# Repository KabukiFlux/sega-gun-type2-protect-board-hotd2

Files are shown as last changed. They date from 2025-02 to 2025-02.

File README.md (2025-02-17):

# SEGA Gun type II Input Protection Board for *The House of the Dead 2* 

This repository contains the **KiCAD project files** for the **Gun II Input Protection Board (GIPB)**, a component designed to help protect the gun sensors in *The House of the Dead 2* arcade machines. The design is based on SEGA's **Service Bulletin (09/10/2002)**, which introduced this board to prevent or minimize damage to the **Gun Sense Board** and **LED Boards** caused by connection issues.

## Table of contents

- [Why](#why)
- [Description](#-description)
- [Schematics](#-schematics)
- [Installation Guide](#-installation-guide)
- [Repository contents](#-repository-contents)

## Why?

This was done during some live events on Twitch.tv and tested for some time.

This is a must have for people using the arcade cabinet for guns on a hostile environment

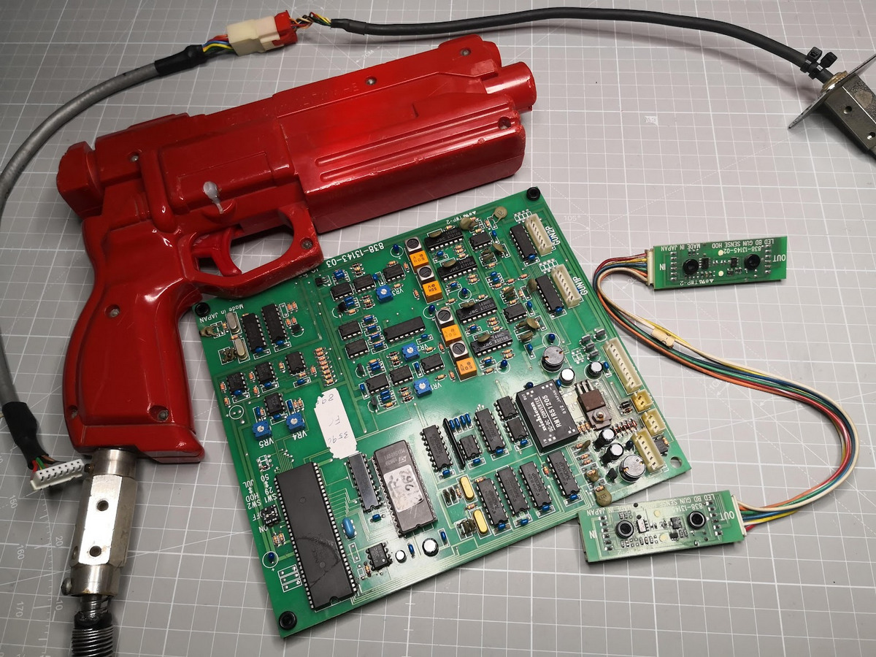
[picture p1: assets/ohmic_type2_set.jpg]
OHMIC Set


## 📜 Description

Over time, disconnections or improper handling of the gun harnesses can lead to damage in the **Gun Sense Board** or **LED Boards**, potentially rendering the guns non-functional. SEGA introduced this **Gun Input Protection Board** to mitigate this issue. While it **does not repair faulty hardware**, it acts as a safeguard against further damage, extending the lifespan of the arcade cabinet's gun system.  

- **Protects the Gun Sense Board & LED Boards** from connection-related damage  
- **Compatible with original HOTD2 and JPLW arcade hardware**  
- **Straightforward installation** – integrates between the gun harness and the Gun Sense Board  
- **Includes KiCAD project files** for custom PCB manufacturing  

## 📝 Schematics

This is the schematics:

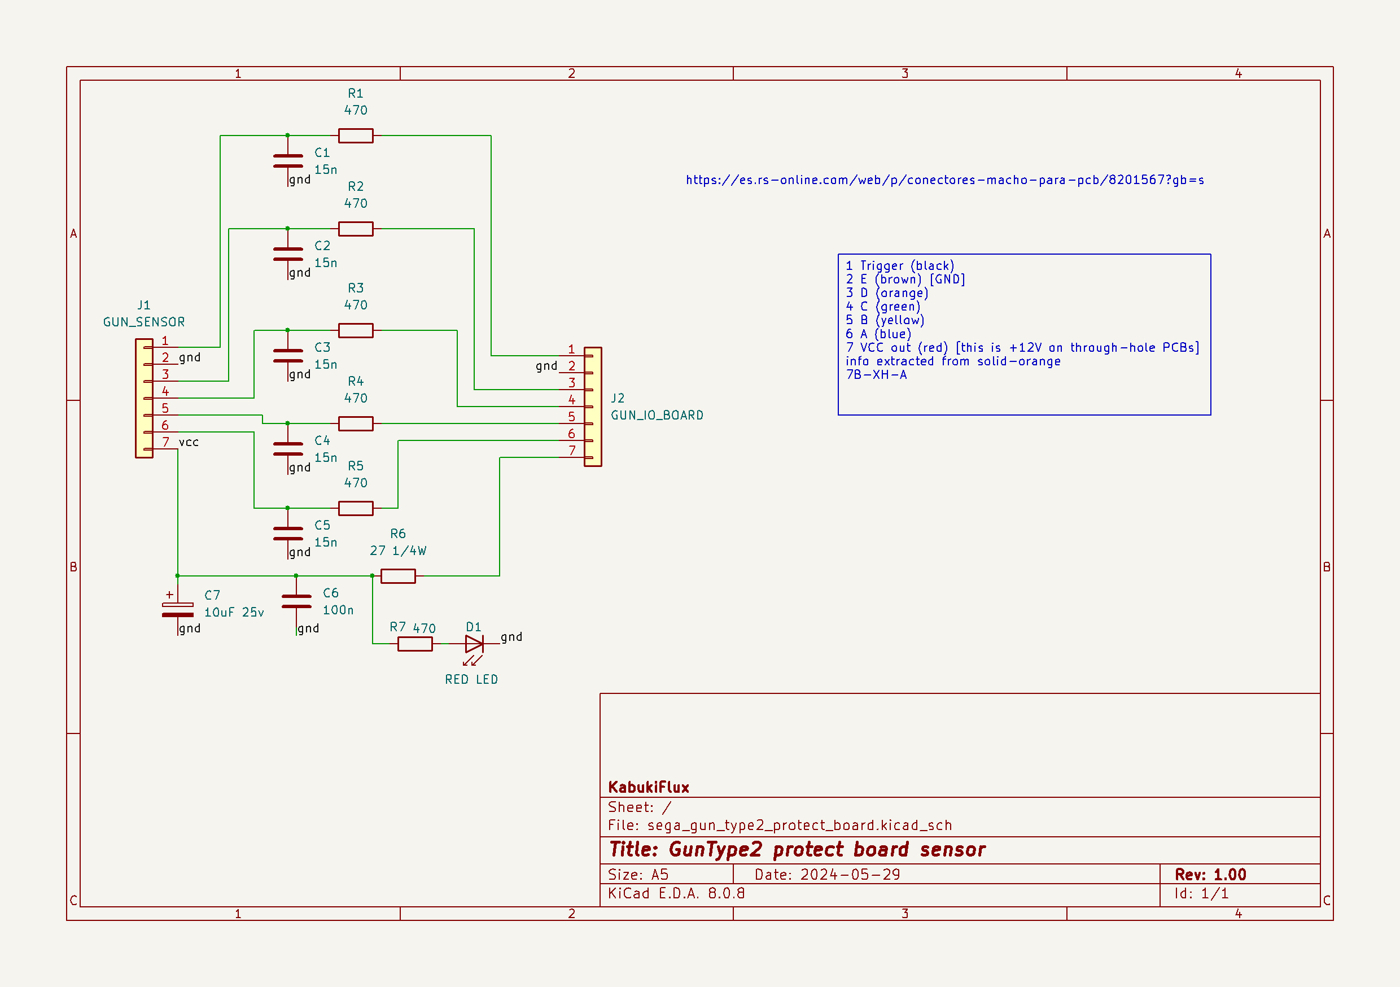
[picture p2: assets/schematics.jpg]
Schematics


## 🛠️ Installation Guide  

### 1️⃣ Preparation  

1- Send to manufacture the GERBER board to [JLCPCB](https://jlcpcb.com/) or other PCB manufacturer.

2- Get the components required, you can see here the Bill Of Materials [BOM](bom/ibom.html)

3- Solder the components.

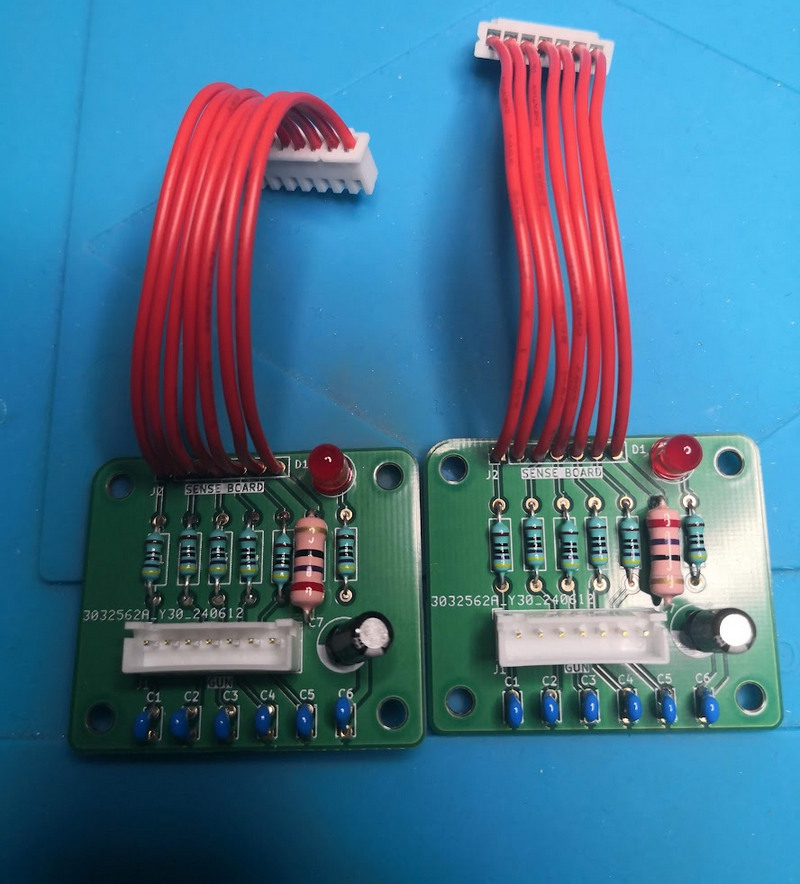
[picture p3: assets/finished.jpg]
Gun protect board


Before installing the board, ensure that:  
- The **Gun Sense Board** and **guns are fully functional**  
- The **arcade cabinet is powered off**  

### 2️⃣ Installation Steps  
1. Locate the **Gun Sense Board** inside the arcade machine.  
2. Disconnect the gun harnesses from the **GUN1P** and **GUN2P** ports.  
3. Take the **Gun Input Protection Board (GIPB)** and connect its labeled **GUN1P** and **GUN2P** connectors to the corresponding ports on the **Gun Sense Board**.  
4. Reconnect Player 1’s (Blue Gun) harness into **GUN1P** on the **Protection Board**.  
5. Reconnect Player 2’s (Red Gun) harness into **GUN2P** on the **Protection Board**.  
6. Secure the **Protection Board** using the provided spacers and screws.  
7. Power on the arcade cabinet and enter **Self-Test Mode**.  
8. Navigate to **Gun Settings** and recalibrate the guns.  

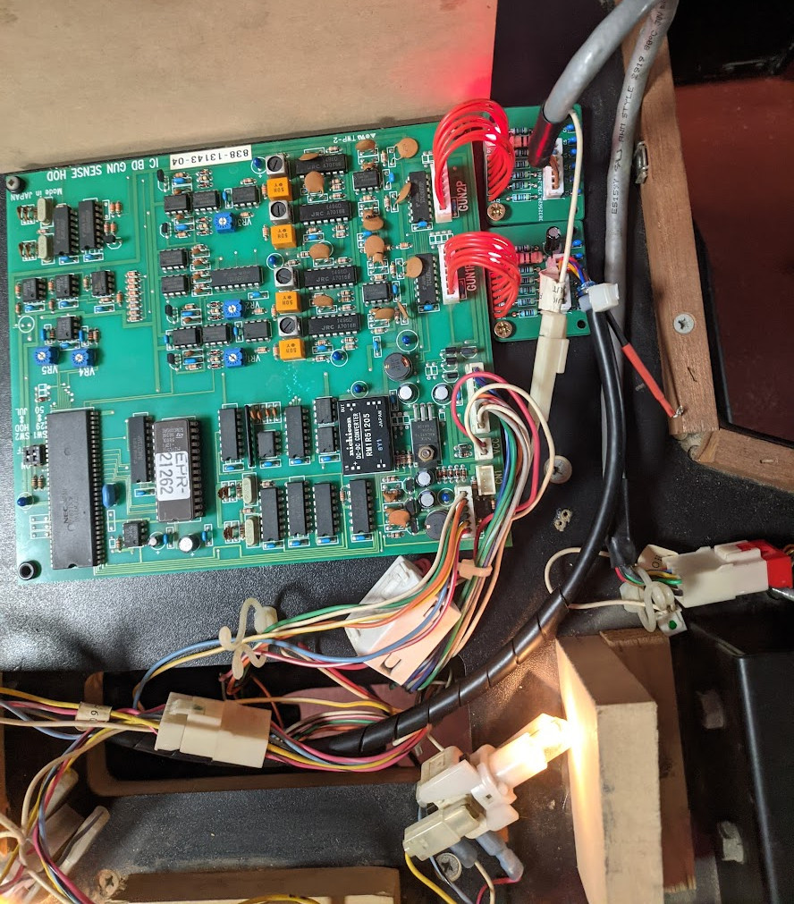
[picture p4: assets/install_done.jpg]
Finished install


## 📝 Repository Contents  

- **`/kicad/`** – KiCAD design files for the **Gun Input Protection Board**  
- **`/bom/`** – Circuit parts and assembly for reference  
- **`/gerbers/`** – Gerber files for PCB fabrication  
- **`/DOC/`** – Original bulletin

## 📢 Disclaimer  

I'm not responsible
===================
And yes, read below, no liability is assumed for misuse.

DISCLAIMER (See Licensing)
==========================
See LICENSE fo more information. 

This project is intended for preservation and repair purposes. **Use at your own risk.** The original SEGA hardware must be in **good working condition** before installation. This repository is **not affiliated with SEGA**.

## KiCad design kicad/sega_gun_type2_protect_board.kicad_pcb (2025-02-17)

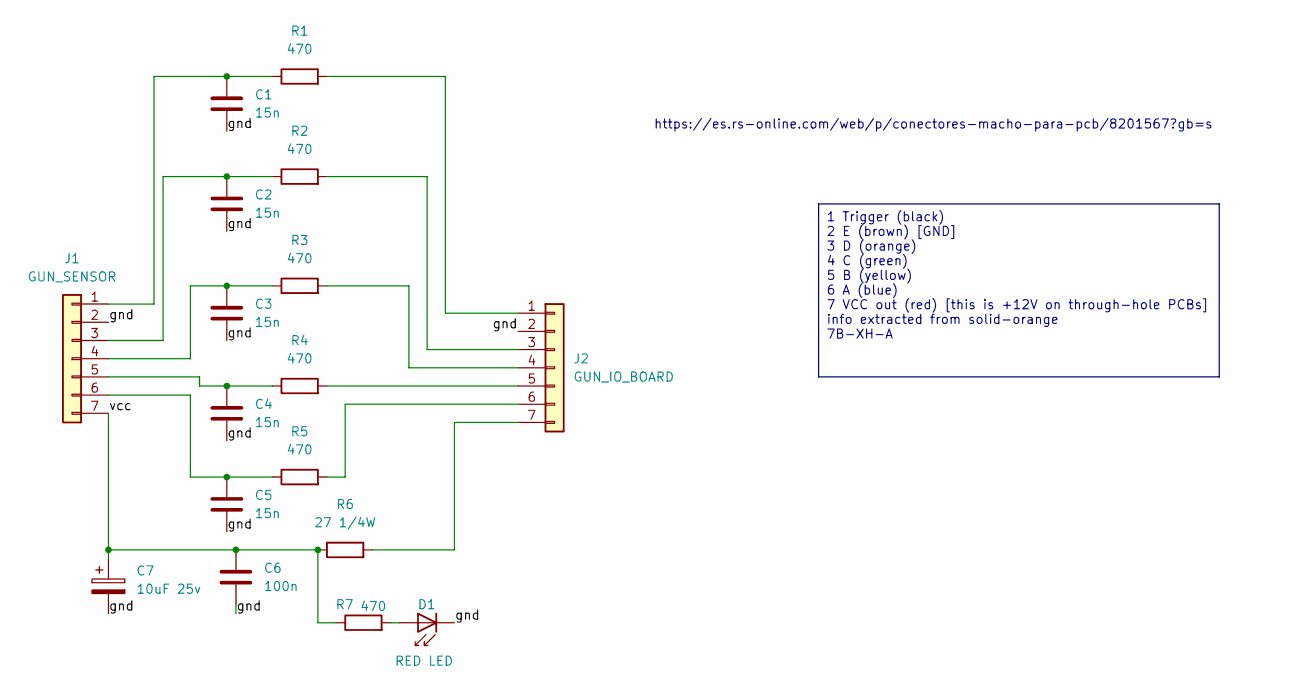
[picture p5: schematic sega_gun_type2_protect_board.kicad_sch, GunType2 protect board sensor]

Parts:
C1, C2, C3, C4, C5: 15n; C_Disc_D3.4mm_W2.1mm_P2.50mm
C6: 100n; C_Disc_D3.4mm_W2.1mm_P2.50mm
C7: 10uF 25v; CP_Radial_D6.3mm_P2.50mm
D1: RED LED; LED_D5.0mm_IRGrey
J1: GUN_SENSOR; JST_XH_B7B-XH-A_1x07_P2.50mm_Vertical
J2: GUN_IO_BOARD; PinHeader_1x07_P2.54mm_Vertical
R1, R2, R3, R4, R5, R7: 470; R_Axial_DIN0207_L6.3mm_D2.5mm_P10.16mm_Horizontal
R6: 27 1/4W; R_Axial_DIN0207_L6.3mm_D2.5mm_P10.16mm_Horizontal

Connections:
/gnd: C1.2, C2.1, C3.1, C4.1, C5.1, C6.1, C7.2, D1.1 (K), J1.2, J2.2
/vcc: C6.2, C7.1, J1.7, R6.1, R7.1
unnamed: D1.2 (A), R7.2
unnamed: C1.1, J1.1, R1.1
unnamed: C2.2, J1.3, R2.1
unnamed: C3.2, J1.4, R3.1
unnamed: C4.2, J1.5, R4.1
unnamed: C5.2, J1.6, R5.1
unnamed: J2.1, R1.2
unnamed: J2.3, R2.2
unnamed: J2.4, R3.2
unnamed: J2.5, R4.2
unnamed: J2.6, R5.2
unnamed: J2.7, R6.2

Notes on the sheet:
1 Trigger (black) 2 E (brown) [GND] 3 D (orange) 4 C (green) 5 B (yellow) 6 A (blue) 7 VCC out (red) [this is +12V on through-hole PCBs] info extracted from solid-orange 7B-XH-A
https://es.rs-online.com/web/p/conectores-macho-para-pcb/8201567?gb=s

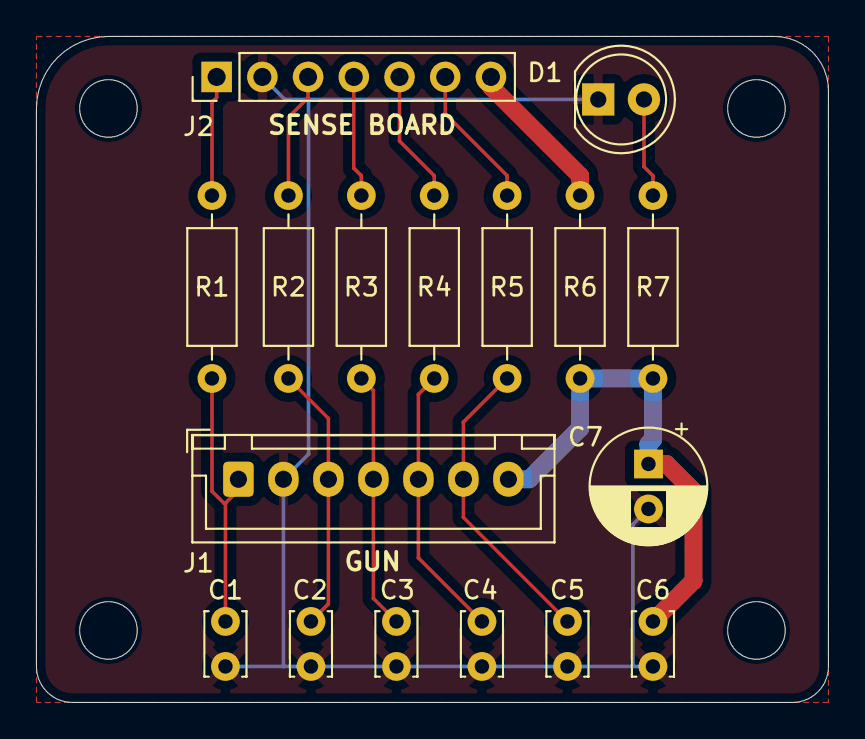
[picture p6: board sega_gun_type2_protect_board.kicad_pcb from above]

Board: 2 copper layers, 44.0 x 37.0 mm, 21 parts (0 on the bottom side), 14 nets.

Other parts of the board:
REF1, REF2, REF3, REF4: MountingHole_3.2mm_M3
